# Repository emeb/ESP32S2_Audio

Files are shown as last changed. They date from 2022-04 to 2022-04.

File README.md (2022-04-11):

# ESP32S2_Audio
A Eurorack module demonstrating the use of the ESP32S2 as an audio effects processor

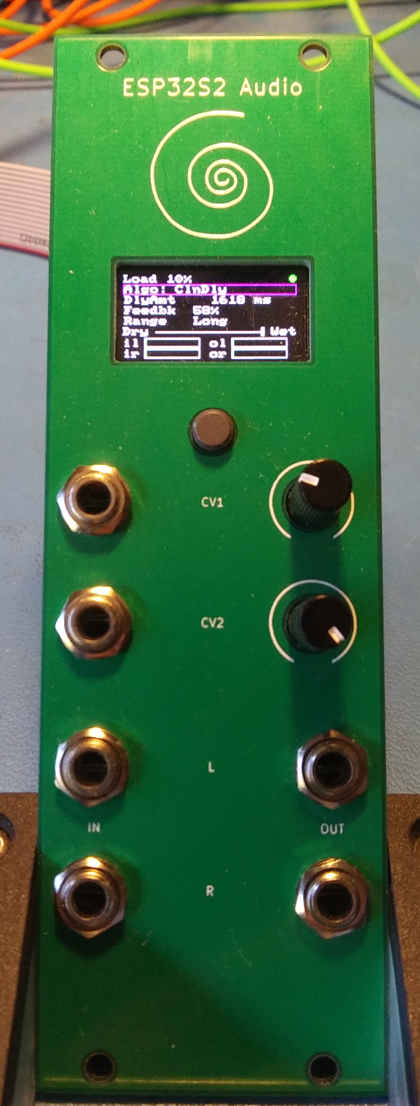
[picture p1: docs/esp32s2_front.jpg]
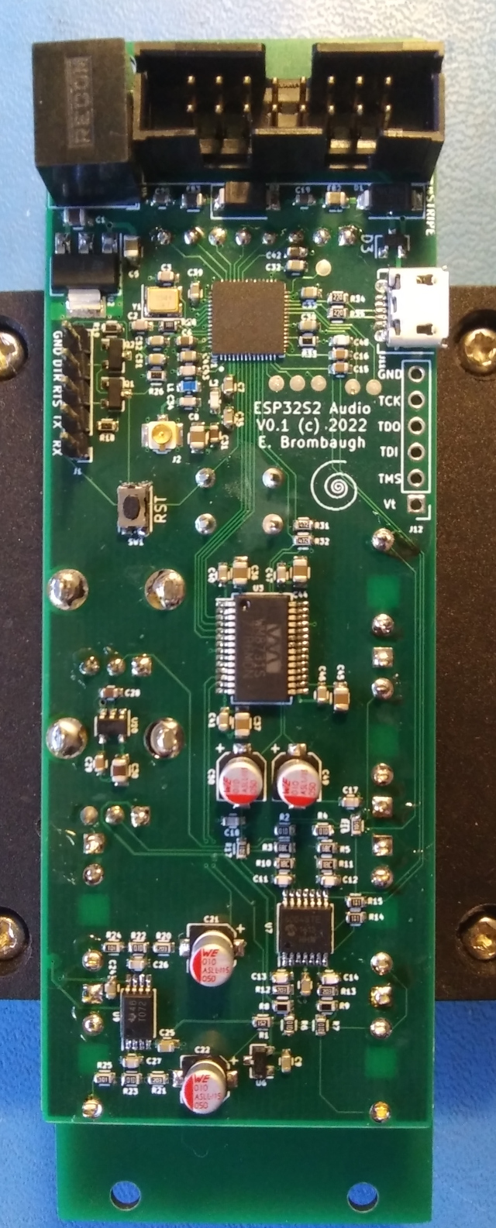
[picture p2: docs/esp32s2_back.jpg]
  

## Abstract
Blah Blah Blah 2020 Microcontroller shortage. See my RP2040_Audio project
if you really want to read all my whinging about this topic:

https://github.com/emeb/RP2040_Audio

So yeah - I've been using STM32 for so long that I was ignoring all this other
stuff that was coming out, including these nifty IoT SoCs (more TLAS pls!) that
so many folks have been using for the lst few years. Espressif has quite a
family of them with a wide variety of capabilities. The ESP32-S2FN4R2 is
especially interesting because it's got 4MB flash and 2MB PSRAM included in
the package and the price is only a few cents more than the raw part. So I
grabbed some devboards, did proof-of-concept on a breadboard and started a
new hardware design. This one is remarkably similar to the RP2040 project
mentioned above - basically I lifted the entire circuit, layout and all and
then proceeded to jack it up on the grease rack and swap the engine out. Here's
the result.

This project is a feasibility study of using the ESP32S2 MCU as an audio effects
processor, with particular emphasis on performance with challenging DSP.

## Hardware
The complete design consists of two PCBs:
* The system PCB - a single board containg all electrical components. Find it
in the Hardware directory.
* The Front Panel - a PCB-based front panel that conforms to the Eurorack
physical mounting standard. Found in the Hardware/esp32s2_panel directory.

The system PCB has the following features:
* Standard Eurorack 16-pin shrouded power connector
* Two +/-5V CV inputs and associated analog signal conditioning 
* Two +/-7V Audio inputs and associated analog signal conditioning 
* Two +/-7V Audio outputs and associated analog drivers
* WM8731 stereo audio codec
* ESP32S2 with 4MB SPI flash, 2MB PSRAM, USB, JTAG and serial interfaces for
development. The RF antenna connection is also available for playing with WiFi
if I ever get around to it.
* 160 x 80 IPS LCD
* UI button

## Firmware
A demonstration firmware is included that exercises all of the capabilities of
the system, including the LCD, UI button, CV inputs and stereo audio I/O. It is
a basic multi-effects unit that supports a complement of audio DSP algorithms
that are easily extended by adding standardized modules to a data structure.
As provided here just three algorithms are available:
* Simple pass-thru with no processing
* Simple gain control
* Basic "clean delay" with crossfaded deglitching during delay changes.

Other algorithms have been tested including phasers, flangers, frequency shifters,
resampling delays and reverbs, but these are not publicly released at this time.

## Findings
The ESP32S2 is not bad for doing audio, but I found it necessary to do a bit of
hacking on their I2S driver - as delivered in their ESP-IDF V5.0 which I used
here the driver makes some limiting assumptions about how you want to do audio:
Namely that you'll be streaming large buffers to/from some external device like
the WiFi interface or storage. That's *NOT* how I do audio - I want small
buffers streaming in realtime with lots of DSP involved. Consequently, I coded
up a "low-latency" driver that works more the way I want and that's included
here.

The ESP32 ADCs are also noisy and a bit weird to use, so my ADC driver has a
rather kludgy approach to collecting data and applies heavy filtering to clean
things up. The lack of hardware floating point was a bit of a stumbling block
and I spent some time converting a few of my algorithms to work with fixed
point. A few others were fine using floating point in software so those were
left alone. The reasonably large PSRAM works well for smaller-sized buffers
in audio delays and found a lot of use in delays.

I found many other aspects of their system quite pleasant to use - the IDF has
a lot of well thought-out services, and the build process is easy to work with.

TL;DR - ESP32S2 can work well for audio effects. Give it a try!

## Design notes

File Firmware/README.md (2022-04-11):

# ESP32S2 Audio Firmware
This directory contains the source and build scripts for the RP2040 Audio
firmware.

## Features
* Simple graphic user interface for selecting and controlling a variety
of audio DSP algorithms.
* Single button and CV navigation through availble effects and settings.
* Non-volatile storage of effects parameters so user settings will survive
power cycling and restore to the previous configuration.
* Storage "pending" indicator.
* CPU Load meter to indicate how hard the system is working.
* Wet/Dry mix indicator.
* Independent input/output VU meters for both channels.

## Usage
* System shows splash screen with version number at power-up.
* Use the single button to select which screen parameter to edit. Current
parameter highlighted with a magenta box drawn around it.
* Use CV #1 to edit the parameter. There is hysteresis and 'snap' so that you
must move the CV to begin changing the value from the previous setting.
* CV #2 is dedicated to the Wet/Dry mix.

## Building
This project is built using the ESP-IDF V5.0 

https://github.com/espressif/esp-idf

Install the SDK and ensure it's working properly, then within this directory

```shell
idf.py build
```

Then use your method of choice for programming the device

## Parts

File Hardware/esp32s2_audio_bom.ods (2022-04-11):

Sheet: esp32s2_audio_bom
Source: | /home/ericb/KBADC/kicad/esp32s2_audio/esp32s2_audio.sch
Date: | Wed 02 Mar 2022 10:13:31 AM MST
Tool: | Eeschema 5.1.12-1.fc34
Generator: | /usr/share/kicad/plugins/bom_csv_grouped_by_value.py
Component Count: | 117
Individual Components:
Item | Qty | Reference(s) | Value | LibPart | Footprint | Datasheet | ambient temperature range high | ambient temperature range low | automotive | bandwidth | category | data rate | device class L1 | device class L2 | device class L3 | digikey description | digikey part number | height | interface | ipc land pattern name | lead free | library id | manufacturer | max frequency | max junction temp | max supply voltage | min supply voltage | mouser part number | nominal supply current | number of ADC channels | number of GPIO | package | receiving current | rohs | sensitivity | standoff height | temperature range high | temperature range low | transmitting current
 |  | C1 | 10uf | Device:C_Small | Capacitors_SMD:C_0805 | ~
 |  | C2 | 27pf | Device:C_Small | Capacitors_SMD:C_0603 | ~
 |  | C3 | 27pf | Device:C_Small | Capacitors_SMD:C_0603 | ~
 |  | C4 | 0.1uf | Device:C_Small | Capacitors_SMD:C_0603 | ~
 |  | C5 | 10uf | Device:C_Small | Capacitors_SMD:C_0805 | ~
 |  | C6 | 1uf | Device:C_Small | Capacitors_SMD:C_0603 | ~
 |  | C7 | 0.1uf | Device:C_Small | Capacitors_SMD:C_0603 | ~
 |  | C8 | 10uf | Device:C_Small | Capacitors_SMD:C_0805 | ~
 |  | C9 | 0.1uf | Device:C_Small | Capacitors_SMD:C_0603 | ~
 |  | C10 | 0.1uf | Device:C_Small | Capacitors_SMD:C_0603 | ~
 |  | C11 | 330pf | Device:C_Small | Capacitors_SMD:C_0603 | ~
 |  | C12 | 330pf | Device:C_Small | Capacitors_SMD:C_0603 | ~
 |  | C13 | 330pf | Device:C_Small | Capacitors_SMD:C_0603 | ~
 |  | C14 | 330pf | Device:C_Small | Capacitors_SMD:C_0603 | ~
 |  | C15 | 0.01uf | Device:C_Small | Capacitors_SMD:C_0603 | ~
 |  | C16 | 0.01uf | Device:C_Small | Capacitors_SMD:C_0603 | ~
 |  | C17 | 220pf | Device:C_Small | Capacitors_SMD:C_0603 | ~
 |  | C18 | 220pf | Device:C_Small | Capacitors_SMD:C_0603 | ~
 |  | C19 | 1uf | Device:C_Small | Capacitors_SMD:C_0603 | ~
 |  | C20 | 1uf | Device:C_Small | Capacitors_SMD:C_0603 | ~
 |  | C21 | 1uf | Device:CP1 | Capacitors_SMD:CP_Elec_4x5.3 | ~
 |  | C22 | 1uf | Device:CP1 | Capacitors_SMD:CP_Elec_4x5.3 | ~
 |  | C24 | 0.1uf | Device:C_Small | Capacitors_SMD:C_0603 | ~
 |  | C25 | 0.1uf | Device:C_Small | Capacitors_SMD:C_0603 | ~
 |  | C26 | 68pf | Device:C_Small | Capacitors_SMD:C_0603 | ~
 |  | C27 | 68pf | Device:C_Small | Capacitors_SMD:C_0603 | ~
 |  | C28 | 1uf | Device:C_Small | Capacitors_SMD:C_0603 | ~
 |  | C29 | 0.01uf | Device:C_Small | Capacitors_SMD:C_0603 | ~
 |  | C30 | 10uf | Device:C_Small | Capacitors_SMD:C_0805 | ~
 |  | C31 | 1uf | Device:C_Small | Capacitors_SMD:C_0603 | ~
 |  | C32 | 0.1uf | Device:C_Small | Capacitors_SMD:C_0603 | ~
 |  | C33 | 0.1uf | Device:C_Small | Capacitors_SMD:C_0603 | ~
 |  | C34 | 2.6pf | Device:C_Small | Capacitors_SMD:C_0603 | ~
 |  | C35 | 0.1uf | Device:C_Small | Capacitors_SMD:C_0603 | ~
 |  | C36 | 10uf | Device:C_Small | Capacitors_SMD:C_0805 | ~
 |  | C37 | 10uf | Device:C_Small | Capacitors_SMD:C_0805 | ~
 |  | C38 | 0.1uf | Device:C_Small | Capacitors_SMD:C_0603 | ~
 |  | C39 | 0.1uf | Device:C_Small | Capacitors_SMD:C_0603 | ~
 |  | C40 | 0.1uf | Device:C_Small | Capacitors_SMD:C_0603 | ~
 |  | C41 | 0.1uf | Device:C_Small | Capacitors_SMD:C_0603 | ~
 |  | C42 | 1uf | Device:C_Small | Capacitors_SMD:C_0603 | ~
 |  | C43 | 3pf | Device:C_Small | Capacitors_SMD:C_0603 | ~
 |  | C44 | 10uf | Device:C_Small | Capacitors_SMD:C_0805 | ~
 |  | C45 | 10uf | Device:C_Small | Capacitors_SMD:C_0805 | ~
 |  | C46 | 0.1uf | Device:C_Small | Capacitors_SMD:C_0603 | ~
 |  | C47 | 0.1uf | Device:C_Small | Capacitors_SMD:C_0603 | ~
 |  | C48 | 330pf | Device:C_Small | Capacitors_SMD:C_0603 | ~
 |  | C49 | 1uf | Device:CP1 | Capacitors_SMD:CP_Elec_4x5.3 | ~
 |  | C50 | 1uf | Device:CP1 | Capacitors_SMD:CP_Elec_4x5.3 | ~
 |  | C51 | 0.1uf | Device:C_Small | Capacitors_SMD:C_0603 | ~
 |  | C52 | 100pf | Device:C_Small | Capacitors_SMD:C_0603 | ~
 |  | D1 | D | Device:D | Diodes_SMD:D_SMA | ~
 |  | D2 | D | Device:D | Diodes_SMD:D_SMA | ~
 |  | D3 | BAT54C | Diode:BAT54C | Package_TO_SOT_SMD:SOT-23 | http://www.diodes.com/_files/datasheets/ds11005.pdf
 |  | FB2 | 220 | Device:Ferrite_Bead_Small | Resistors_SMD:R_0805 | ~
 |  | FB3 | 220 | Device:Ferrite_Bead_Small | Resistors_SMD:R_0805 | ~
 |  | J1 | Serial | Connector_Generic:Conn_01x05 | Pin_Headers:Pin_Header_Straight_1x05_Pitch2.54mm | ~
 |  | J2 | CONN_CONUFL001-SMD-T_LNX | emeb_library:CONN_CONUFL001-SMD-T_LNX | footprints:CONUFL001-SMD-T | ~
 |  | J3 | LCD | Connector_Generic:Conn_01x08 | footprints:LCD_80x160_0.96 | ~
 |  | J4 | AudioJack2_SwitchT | Connector:AudioJack2_SwitchT | footprints:Jack_3.5mm_QingPu_WQP-PJ398SM_Vertical_CircularHoles | ~
 |  | J5 | AudioJack2_SwitchT | Connector:AudioJack2_SwitchT | footprints:Jack_3.5mm_QingPu_WQP-PJ398SM_Vertical_CircularHoles | ~
 |  | J6 | AudioJack2_SwitchT | Connector:AudioJack2_SwitchT | footprints:Jack_3.5mm_QingPu_WQP-PJ398SM_Vertical_CircularHoles | ~
 |  | J7 | AudioJack2_SwitchT | Connector:AudioJack2_SwitchT | footprints:Jack_3.5mm_QingPu_WQP-PJ398SM_Vertical_CircularHoles | ~
 |  | J8 | Conn_02x08_Odd_Even | Connector_Generic:Conn_02x08_Odd_Even | footprints:5103308-3 | ~
 |  | J9 | AudioJack2_SwitchT | Connector:AudioJack2_SwitchT | footprints:Jack_3.5mm_QingPu_WQP-PJ398SM_Vertical_CircularHoles | ~
 |  | J10 | AudioJack2_SwitchT | Connector:AudioJack2_SwitchT | footprints:Jack_3.5mm_QingPu_WQP-PJ398SM_Vertical_CircularHoles | ~
 |  | J11 | USB_B_Micro | Connector:USB_B_Micro | footprints:USB_Micro-B_10103594-0001LF_actual_outline | ~
 |  | J12 | JTAG | Connector_Generic:Conn_01x06 | Pin_Headers:Pin_Header_Straight_1x06_Pitch2.54mm | ~
 |  | L1 | 2.4nH | Device:L | Capacitor_SMD:C_0603_1608Metric | ~
 |  | L2 | 2.2nH 500ma | Device:L | Capacitor_SMD:C_0603_1608Metric | ~
 |  | Q1 | MMBT3904 | Device:Q_NPN_BEC | TO_SOT_Packages_SMD:SOT-23 | ~
 |  | Q2 | MMBT3904 | Device:Q_NPN_BEC | TO_SOT_Packages_SMD:SOT-23 | ~
 |  | R1 | 1.5k | Device:R | Resistors_SMD:R_0603 | ~
 |  | R2 | 100k | Device:R | Resistors_SMD:R_0603 | ~
 |  | R3 | 49.9k | Device:R | Resistors_SMD:R_0603 | ~
 |  | R4 | 100k | Device:R | Resistors_SMD:R_0603 | ~
 |  | R5 | 49.9k | Device:R | Resistors_SMD:R_0603 | ~
 |  | R6 | 100k | Device:R | Resistors_SMD:R_0603 | ~
 |  | R7 | 100k | Device:R | Resistors_SMD:R_0603 | ~
 |  | R8 | 60.4k | Device:R | Resistors_SMD:R_0603 | ~
 |  | R9 | 60.4k | Device:R | Resistors_SMD:R_0603 | ~
 |  | R10 | 33k | Device:R | Resistors_SMD:R_0603 | ~
 |  | R11 | 33k | Device:R | Resistors_SMD:R_0603 | ~
 |  | R12 | 20k | Device:R | Resistors_SMD:R_0603 | ~
 |  | R13 | 20k | Device:R | Resistors_SMD:R_0603 | ~
 |  | R14 | 180 | Device:R | Resistors_SMD:R_0603 | ~
 |  | R15 | 180 | Device:R | Resistors_SMD:R_0603 | ~
 |  | R16 | 100 | Device:R | Resistors_SMD:R_0603 | ~
 |  | R17 | 100 | Device:R | Resistors_SMD:R_0603 | ~
 |  | R18 | 10k | Device:R | Resistors_SMD:R_0603 | ~
 |  | R19 | 10k | Device:R | Resistors_SMD:R_0603 | ~
 |  | R20 | 20k | Device:R | Resistors_SMD:R_0603 | ~
 |  | R21 | 20k | Device:R | Resistors_SMD:R_0603 | ~
 |  | R22 | 100k | Device:R | Resistors_SMD:R_0603 | ~
 |  | R23 | 100k | Device:R | Resistors_SMD:R_0603 | ~
 |  | R24 | 100 | Device:R | Resistors_SMD:R_0603 | ~
 |  | R25 | 100 | Device:R | Resistors_SMD:R_0603 | ~
 |  | R26 | 10k | Device:R | Resistors_SMD:R_0603 | ~
 |  | R28 | 1k | Device:R | Resistors_SMD:R_0603 | ~
 |  | R31 | 4.7k | Device:R | Resistors_SMD:R_0603 | ~
 |  | R32 | 4.7k | Device:R | Resistors_SMD:R_0603 | ~
 |  | R33 | 49 | Device:R | Resistors_SMD:R_0603 | ~
 |  | R34 | 27.5 | Device:R | Resistors_SMD:R_0603 | ~
 |  | R35 | 27.5 | Device:R | Resistors_SMD:R_0603 | ~
 |  | RV1 | 10k | Device:R_POT | footprints:Potentiometer_TT_P0915N | ~
 |  | RV2 | 10k | Device:R_POT | footprints:Potentiometer_TT_P0915N | ~
 |  | SW1 | SW_Push | Switch:SW_Push | Buttons_Switches_SMD:SW_SPST_KMR2 | ~
 |  | SW4 | SW_Push | Switch:SW_Push | footprints:SW_PUSH_6mm_Center | ~
 |  | U1 | ESP32-S2 | emeb_library:ESP32-S2_emeb | footprints:Espressif_Systems-ESP32-S2-IPC_A | https://www.espressif.com/sites/default/files/documentation/esp32-s2_datasheet_en.pdf | +105Â°C | -40Â°C | No | 40MHz | IC | 150Mbits/s | Integrated Circuits (ICs) | RF Semiconductors and Devices | Transceivers | RX TXRX MOD WIFI SURFACE MOUNT | 1965-ESP32-S2TR-ND | 0.9mm | I2C,SPI,UART,USB,I2S,Other | QFN40P700X700X85-56 | Yes | aeb43a67ce7aabf7 | Espressif Systems | 2.4GHz | +125Â°C | 3.6V | 1.8V | 356-ESP32-S2 | 0.5A | 20 | 43 | QFN56 | 68mA | Yes | -97dBm | 0mm | +105Â°C | -40Â°C | 310mA
 |  | U2 | LD1117S33TR_SOT223 | Regulator_Linear:LD1117S33TR_SOT223 | Package_TO_SOT_SMD:SOT-223-3_TabPin2 | http://www.st.com/st-web-ui/static/active/en/resource/technical/document/datasheet/CD00000544.pdf
 |  | U3 | WM8731 | emeb_library:WM8731 | Housings_SSOP:SSOP-28_5.3x10.2mm_Pitch0.65mm
 |  | U4 | R-78E5.0-0.5 | emeb_library:R-78E5.0-0.5 | Converter_DCDC:Converter_DCDC_RECOM_R-78E-0.5_THT | https://www.recom-power.com/pdf/Innoline/R-78Exx-0.5.pdf
 |  | U6 | LM4040DBZ-5 | Reference_Voltage:LM4040DBZ-5 | Package_TO_SOT_SMD:SOT-23 | http://www.ti.com/lit/ds/symlink/lm4040-n.pdf
 |  | U7 | MCP6004 | Amplifier_Operational:MCP6004 | Housings_SSOP:TSSOP-14_4.4x5mm_Pitch0.65mm | http://www.ti.com/lit/ds/symlink/tl081.pdf
 |  | U9 | TL072PW | Amplifier_Operational:TL082 | Housings_SSOP:TSSOP-8_4.4x3mm_Pitch0.65mm | http://www.ti.com/lit/ds/symlink/tl081.pdf
 |  | U10 | LP2985-3.3 | Regulator_Linear:LP2985-3.3 | TO_SOT_Packages_SMD:SOT-23-5 | http://www.ti.com/lit/ds/symlink/lp2985.pdf
 |  | Y1 | Crystal_4pin_SMD | emeb_library:Crystal_4pin_SMD | Crystals:Crystal_SMD_3225-4pin_3.2x2.5mm
Collated Components:
Item | Qty | Reference(s) | Value | LibPart | Footprint | Datasheet | ambient temperature range high | ambient temperature range low | automotive | bandwidth | category | data rate | device class L1 | device class L2 | device class L3 | digikey description | digikey part number | height | interface | ipc land pattern name | lead free | library id | manufacturer | max frequency | max junction temp | max supply voltage | min supply voltage | mouser part number | nominal supply current | number of ADC channels | number of GPIO | package | receiving current | rohs | sensitivity | standoff height | temperature range high | temperature range low | transmitting current
1 | 8 | C1, C5, C8, C30, C36, C37, C44, C45 | 10uf | Device:C_Small | Capacitors_SMD:C_0805 | ~
2 | 2 | C2, C3 | 27pf | Device:C_Small | Capacitors_SMD:C_0603 | ~
3 | 16 | C4, C7, C9, C10, C24, C25, C32, C33, C35, C38, C39, C40, C41, C46, C47, C51 | 0.1uf | Device:C_Small | Capacitors_SMD:C_0603 | ~
4 | 6 | C6, C19, C20, C28, C31, C42 | 1uf | Device:C_Small | Capacitors_SMD:C_0603 | ~
5 | 5 | C11, C12, C13, C14, C48 | 330pf | Device:C_Small | Capacitors_SMD:C_0603 | ~
6 | 3 | C15, C16, C29 | 0.01uf | Device:C_Small | Capacitors_SMD:C_0603 | ~
7 | 2 | C17, C18 | 220pf | Device:C_Small | Capacitors_SMD:C_0603 | ~
8 | 4 | C21, C22, C49, C50 | 1uf | Device:CP1 | Capacitors_SMD:CP_Elec_4x5.3 | ~
9 | 2 | C26, C27 | 68pf | Device:C_Small | Capacitors_SMD:C_0603 | ~
10 | 1 | C34 | 2.6pf | Device:C_Small | Capacitors_SMD:C_0603 | ~
11 | 1 | C43 | 3pf | Device:C_Small | Capacitors_SMD:C_0603 | ~
12 | 1 | C52 | 100pf | Device:C_Small | Capacitors_SMD:C_0603 | ~
13 | 2 | D1, D2 | D | Device:D | Diodes_SMD:D_SMA | ~
14 | 1 | D3 | BAT54C | Diode:BAT54C | Package_TO_SOT_SMD:SOT-23 | http://www.diodes.com/_files/datasheets/ds11005.pdf
15 | 2 | FB2, FB3 | 220 | Device:Ferrite_Bead_Small | Resistors_SMD:R_0805 | ~
16 | 1 | J1 | Serial | Connector_Generic:Conn_01x05 | Pin_Headers:Pin_Header_Straight_1x05_Pitch2.54mm | ~
17 | 1 | J2 | CONN_CONUFL001-SMD-T_LNX | emeb_library:CONN_CONUFL001-SMD-T_LNX | footprints:CONUFL001-SMD-T | ~
18 | 1 | J3 | LCD | Connector_Generic:Conn_01x08 | footprints:LCD_80x160_0.96 | ~
19 | 6 | J4, J5, J6, J7, J9, J10 | AudioJack2_SwitchT | Connector:AudioJack2_SwitchT | footprints:Jack_3.5mm_QingPu_WQP-PJ398SM_Vertical_CircularHoles | ~
20 | 1 | J8 | Conn_02x08_Odd_Even | Connector_Generic:Conn_02x08_Odd_Even | footprints:5103308-3 | ~
21 | 1 | J11 | USB_B_Micro | Connector:USB_B_Micro | footprints:USB_Micro-B_10103594-0001LF_actual_outline | ~
22 | 1 | J12 | JTAG | Connector_Generic:Conn_01x06 | Pin_Headers:Pin_Header_Straight_1x06_Pitch2.54mm | ~
23 | 1 | L1 | 2.4nH | Device:L | Capacitor_SMD:C_0603_1608Metric | ~
24 | 1 | L2 | 2.2nH 500ma | Device:L | Capacitor_SMD:C_0603_1608Metric | ~
25 | 2 | Q1, Q2 | MMBT3904 | Device:Q_NPN_BEC | TO_SOT_Packages_SMD:SOT-23 | ~
26 | 1 | R1 | 1.5k | Device:R | Resistors_SMD:R_0603 | ~
27 | 6 | R2, R4, R6, R7, R22, R23 | 100k | Device:R | Resistors_SMD:R_0603 | ~
28 | 2 | R3, R5 | 49.9k | Device:R | Resistors_SMD:R_0603 | ~
29 | 2 | R8, R9 | 60.4k | Device:R | Resistors_SMD:R_0603 | ~
30 | 2 | R10, R11 | 33k | Device:R | Resistors_SMD:R_0603 | ~
31 | 4 | R12, R13, R20, R21 | 20k | Device:R | Resistors_SMD:R_0603 | ~
32 | 2 | R14, R15 | 180 | Device:R | Resistors_SMD:R_0603 | ~
33 | 4 | R16, R17, R24, R25 | 100 | Device:R | Resistors_SMD:R_0603 | ~
34 | 3 | R18, R19, R26 | 10k | Device:R | Resistors_SMD:R_0603 | ~
35 | 1 | R28 | 1k | Device:R | Resistors_SMD:R_0603 | ~
36 | 2 | R31, R32 | 4.7k | Device:R | Resistors_SMD:R_0603 | ~
37 | 1 | R33 | 49 | Device:R | Resistors_SMD:R_0603 | ~
38 | 2 | R34, R35 | 27.5 | Device:R | Resistors_SMD:R_0603 | ~
39 | 2 | RV1, RV2 | 10k | Device:R_POT | footprints:Potentiometer_TT_P0915N | ~
40 | 1 | SW1 | SW_Push | Switch:SW_Push | Buttons_Switches_SMD:SW_SPST_KMR2 | ~
41 | 1 | SW4 | SW_Push | Switch:SW_Push | footprints:SW_PUSH_6mm_Center | ~
42 | 1 | U1 | ESP32-S2 | emeb_library:ESP32-S2_emeb | footprints:Espressif_Systems-ESP32-S2-IPC_A | https://www.espressif.com/sites/default/files/documentation/esp32-s2_datasheet_en.pdf | +105Â°C | -40Â°C | No | 40MHz | IC | 150Mbits/s | Integrated Circuits (ICs) | RF Semiconductors and Devices | Transceivers | RX TXRX MOD WIFI SURFACE MOUNT | 1965-ESP32-S2TR-ND | 0.9mm | I2C,SPI,UART,USB,I2S,Other | QFN40P700X700X85-56 | Yes | aeb43a67ce7aabf7 | Espressif Systems | 2.4GHz | +125Â°C | 3.6V | 1.8V | 356-ESP32-S2 | 0.5A | 20 | 43 | QFN56 | 68mA | Yes | -97dBm | 0mm | +105Â°C | -40Â°C | 310mA
43 | 1 | U2 | LD1117S33TR_SOT223 | Regulator_Linear:LD1117S33TR_SOT223 | Package_TO_SOT_SMD:SOT-223-3_TabPin2 | http://www.st.com/st-web-ui/static/active/en/resource/technical/document/datasheet/CD00000544.pdf
44 | 1 | U3 | WM8731 | emeb_library:WM8731 | Housings_SSOP:SSOP-28_5.3x10.2mm_Pitch0.65mm
45 | 1 | U4 | R-78E5.0-0.5 | emeb_library:R-78E5.0-0.5 | Converter_DCDC:Converter_DCDC_RECOM_R-78E-0.5_THT | https://www.recom-power.com/pdf/Innoline/R-78Exx-0.5.pdf
46 | 1 | U6 | LM4040DBZ-5 | Reference_Voltage:LM4040DBZ-5 | Package_TO_SOT_SMD:SOT-23 | http://www.ti.com/lit/ds/symlink/lm4040-n.pdf
47 | 1 | U7 | MCP6004 | Amplifier_Operational:MCP6004 | Housings_SSOP:TSSOP-14_4.4x5mm_Pitch0.65mm | http://www.ti.com/lit/ds/symlink/tl081.pdf
48 | 1 | U9 | TL072PW | Amplifier_Operational:TL082 | Housings_SSOP:TSSOP-8_4.4x3mm_Pitch0.65mm | http://www.ti.com/lit/ds/symlink/tl081.pdf
49 | 1 | U10 | LP2985-3.3 | Regulator_Linear:LP2985-3.3 | TO_SOT_Packages_SMD:SOT-23-5 | http://www.ti.com/lit/ds/symlink/lp2985.pdf
50 | 1 | Y1 | Crystal_4pin_SMD | emeb_library:Crystal_4pin_SMD | Crystals:Crystal_SMD_3225-4pin_3.2x2.5mm

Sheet: Sheet2
Item | Qty | Reference(s) | Value | Footprint
1 | 8 | C1, C5, C8, C30, C36, C37, C44, C45 | 10uf | Capacitors_SMD:C_0805
2 | 2 | C2, C3 | 27pf | Capacitors_SMD:C_0603
3 | 16 | C4, C7, C9, C10, C24, C25, C32, C33, C35, C38, C39, C40, C41, C46, C47, C51 | 0.1uf | Capacitors_SMD:C_0603
4 | 6 | C6, C19, C20, C28, C31, C42 | 1uf | Capacitors_SMD:C_0603
5 | 5 | C11, C12, C13, C14, C48 | 330pf | Capacitors_SMD:C_0603
6 | 3 | C15, C16, C29 | 0.01uf | Capacitors_SMD:C_0603
7 | 2 | C17, C18 | 220pf | Capacitors_SMD:C_0603
8 | 4 | C21, C22, C49, C50 | 1uf | Capacitors_SMD:CP_Elec_4x5.3
9 | 2 | C26, C27 | 68pf | Capacitors_SMD:C_0603
10 | 1 | C34 | 2.6pf | Capacitors_SMD:C_0603
11 | 1 | C43 | 3pf | Capacitors_SMD:C_0603
12 | 1 | C52 | 100pf | Capacitors_SMD:C_0603
13 | 2 | D1, D2 | D | Diodes_SMD:D_SMA
14 | 1 | D3 | BAT54C | Package_TO_SOT_SMD:SOT-23
15 | 2 | FB2, FB3 | 220 | Resistors_SMD:R_0805
16 | 1 | J1 | Serial | Pin_Headers:Pin_Header_Straight_1x05_Pitch2.54mm
17 | 1 | J2 | CONN_CONUFL001-SMD-T_LNX | footprints:CONUFL001-SMD-T
18 | 1 | J3 | LCD | footprints:LCD_80x160_0.96
19 | 6 | J4, J5, J6, J7, J9, J10 | AudioJack2_SwitchT | footprints:Jack_3.5mm_QingPu_WQP-PJ398SM_Vertical_CircularHoles
20 | 1 | J8 | Conn_02x08_Odd_Even | footprints:5103308-3
21 | 1 | J11 | USB_B_Micro | footprints:USB_Micro-B_10103594-0001LF_actual_outline
22 | 1 | J12 | JTAG | Pin_Headers:Pin_Header_Straight_1x06_Pitch2.54mm
23 | 1 | L1 | 2.4nH | Capacitor_SMD:C_0603_1608Metric
24 | 1 | L2 | 2.2nH 500ma | Capacitor_SMD:C_0603_1608Metric
25 | 2 | Q1, Q2 | MMBT3904 | TO_SOT_Packages_SMD:SOT-23
26 | 1 | R1 | 1.5k | Resistors_SMD:R_0603
27 | 6 | R2, R4, R6, R7, R22, R23 | 100k | Resistors_SMD:R_0603
28 | 2 | R3, R5 | 49.9k | Resistors_SMD:R_0603
29 | 2 | R8, R9 | 60.4k | Resistors_SMD:R_0603
30 | 2 | R10, R11 | 33k | Resistors_SMD:R_0603
31 | 4 | R12, R13, R20, R21 | 20k | Resistors_SMD:R_0603
32 | 2 | R14, R15 | 180 | Resistors_SMD:R_0603
33 | 4 | R16, R17, R24, R25 | 100 | Resistors_SMD:R_0603
34 | 3 | R18, R19, R26 | 10k | Resistors_SMD:R_0603
35 | 1 | R28 | 1k | Resistors_SMD:R_0603
36 | 2 | R31, R32 | 4.7k | Resistors_SMD:R_0603
37 | 1 | R33 | 49 | Resistors_SMD:R_0603
38 | 2 | R34, R35 | 27.5 | Resistors_SMD:R_0603
39 | 2 | RV1, RV2 | 10k | footprints:Potentiometer_TT_P0915N
40 | 1 | SW1 | SW_Push | Buttons_Switches_SMD:SW_SPST_KMR2
41 | 1 | SW4 | SW_Push | footprints:SW_PUSH_6mm_Center
42 | 1 | U1 | ESP32-S2 | footprints:Espressif_Systems-ESP32-S2-IPC_A
43 | 1 | U2 | LD1117S33TR_SOT223 | Package_TO_SOT_SMD:SOT-223-3_TabPin2
44 | 1 | U3 | WM8731 | Housings_SSOP:SSOP-28_5.3x10.2mm_Pitch0.65mm
45 | 1 | U4 | R-78E5.0-0.5 | Converter_DCDC:Converter_DCDC_RECOM_R-78E-0.5_THT
46 | 1 | U6 | LM4040DBZ-5 | Package_TO_SOT_SMD:SOT-23
47 | 1 | U7 | MCP6004 | Housings_SSOP:TSSOP-14_4.4x5mm_Pitch0.65mm
48 | 1 | U9 | TL072PW | Housings_SSOP:TSSOP-8_4.4x3mm_Pitch0.65mm
49 | 1 | U10 | LP2985-3.3 | TO_SOT_Packages_SMD:SOT-23-5
50 | 1 | Y1 | Crystal_4pin_SMD | Crystals:Crystal_SMD_3225-4pin_3.2x2.5mm

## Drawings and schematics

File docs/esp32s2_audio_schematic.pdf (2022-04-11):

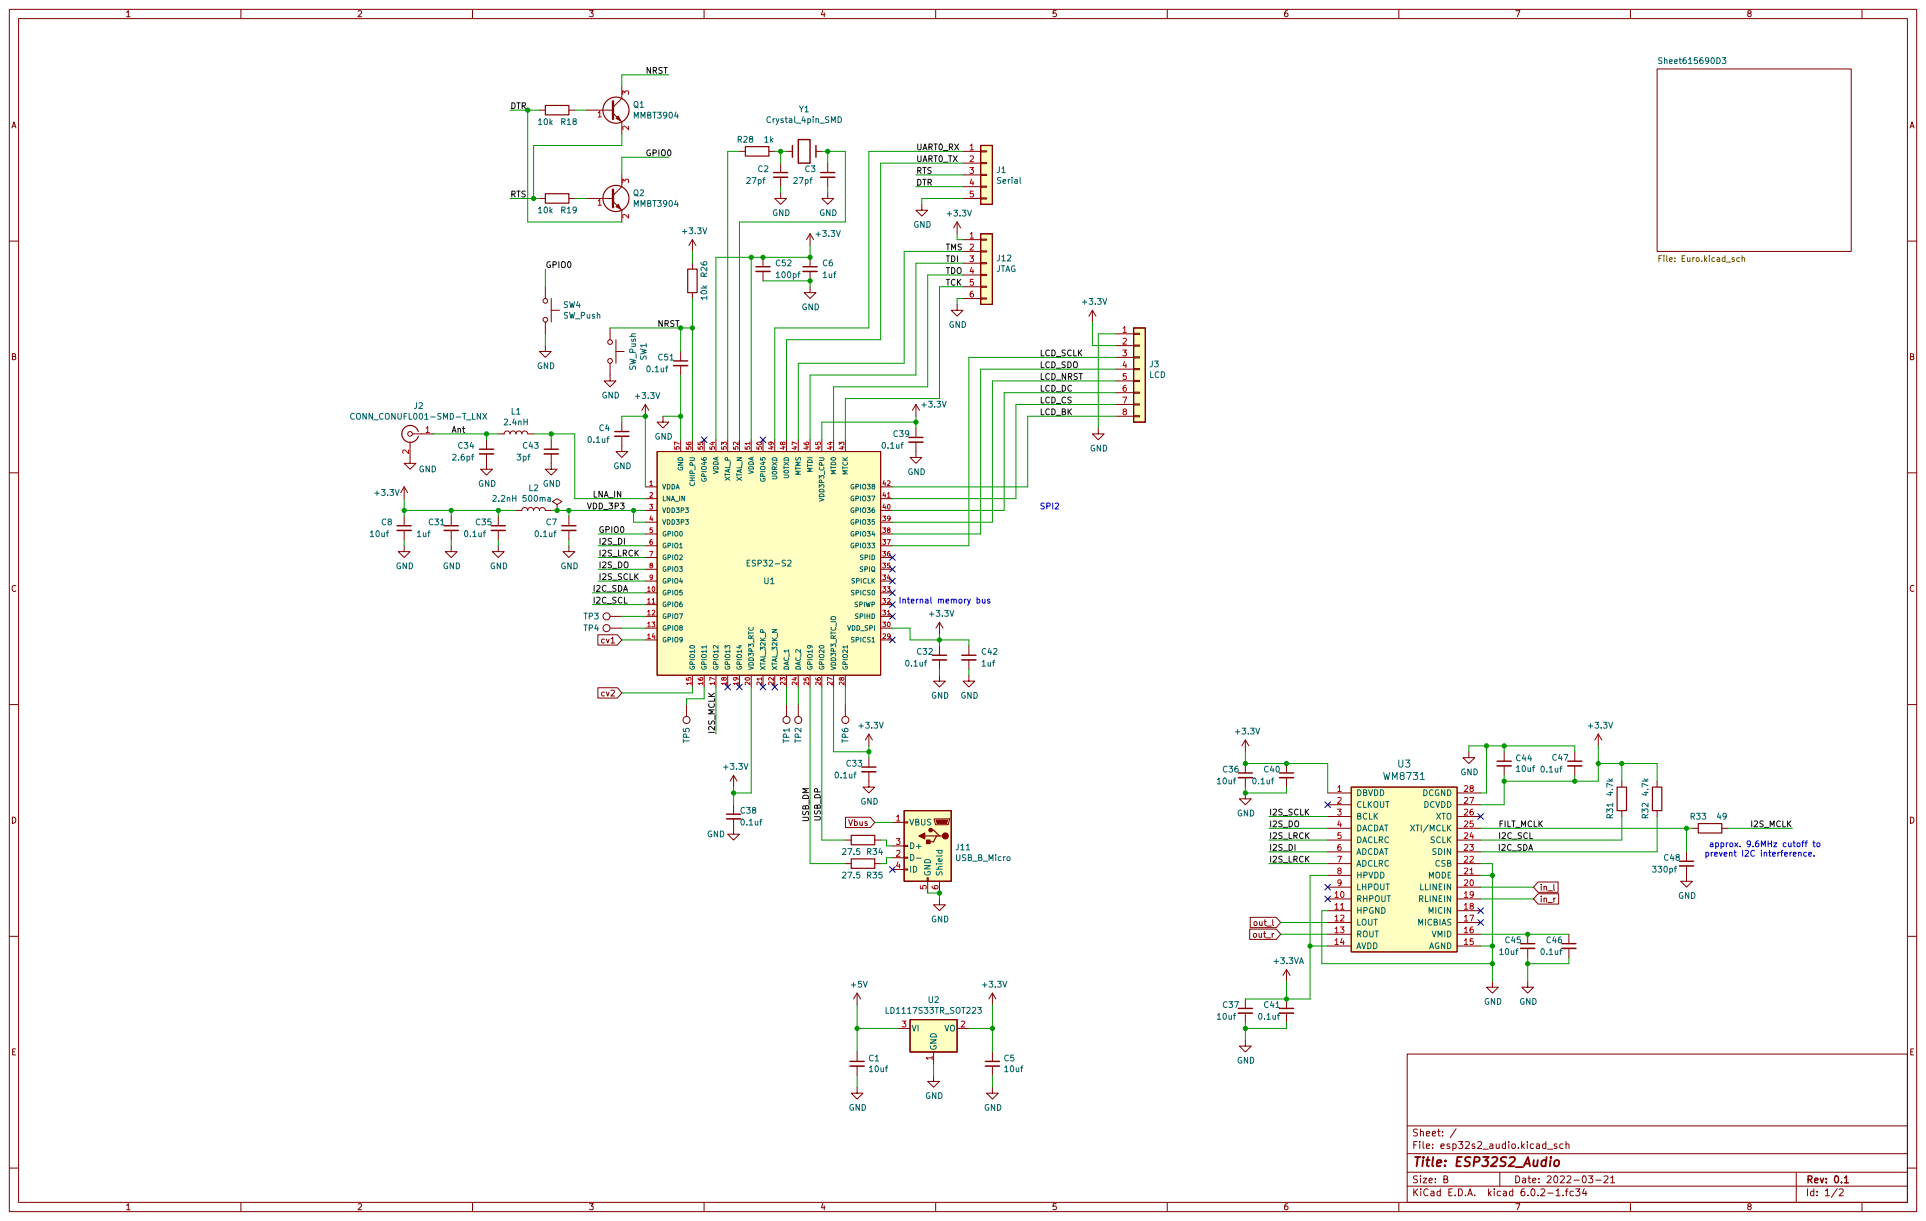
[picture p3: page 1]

LCD_SDO
LCD_NRST
LCD_DC
LCD_CS
LCD_BK

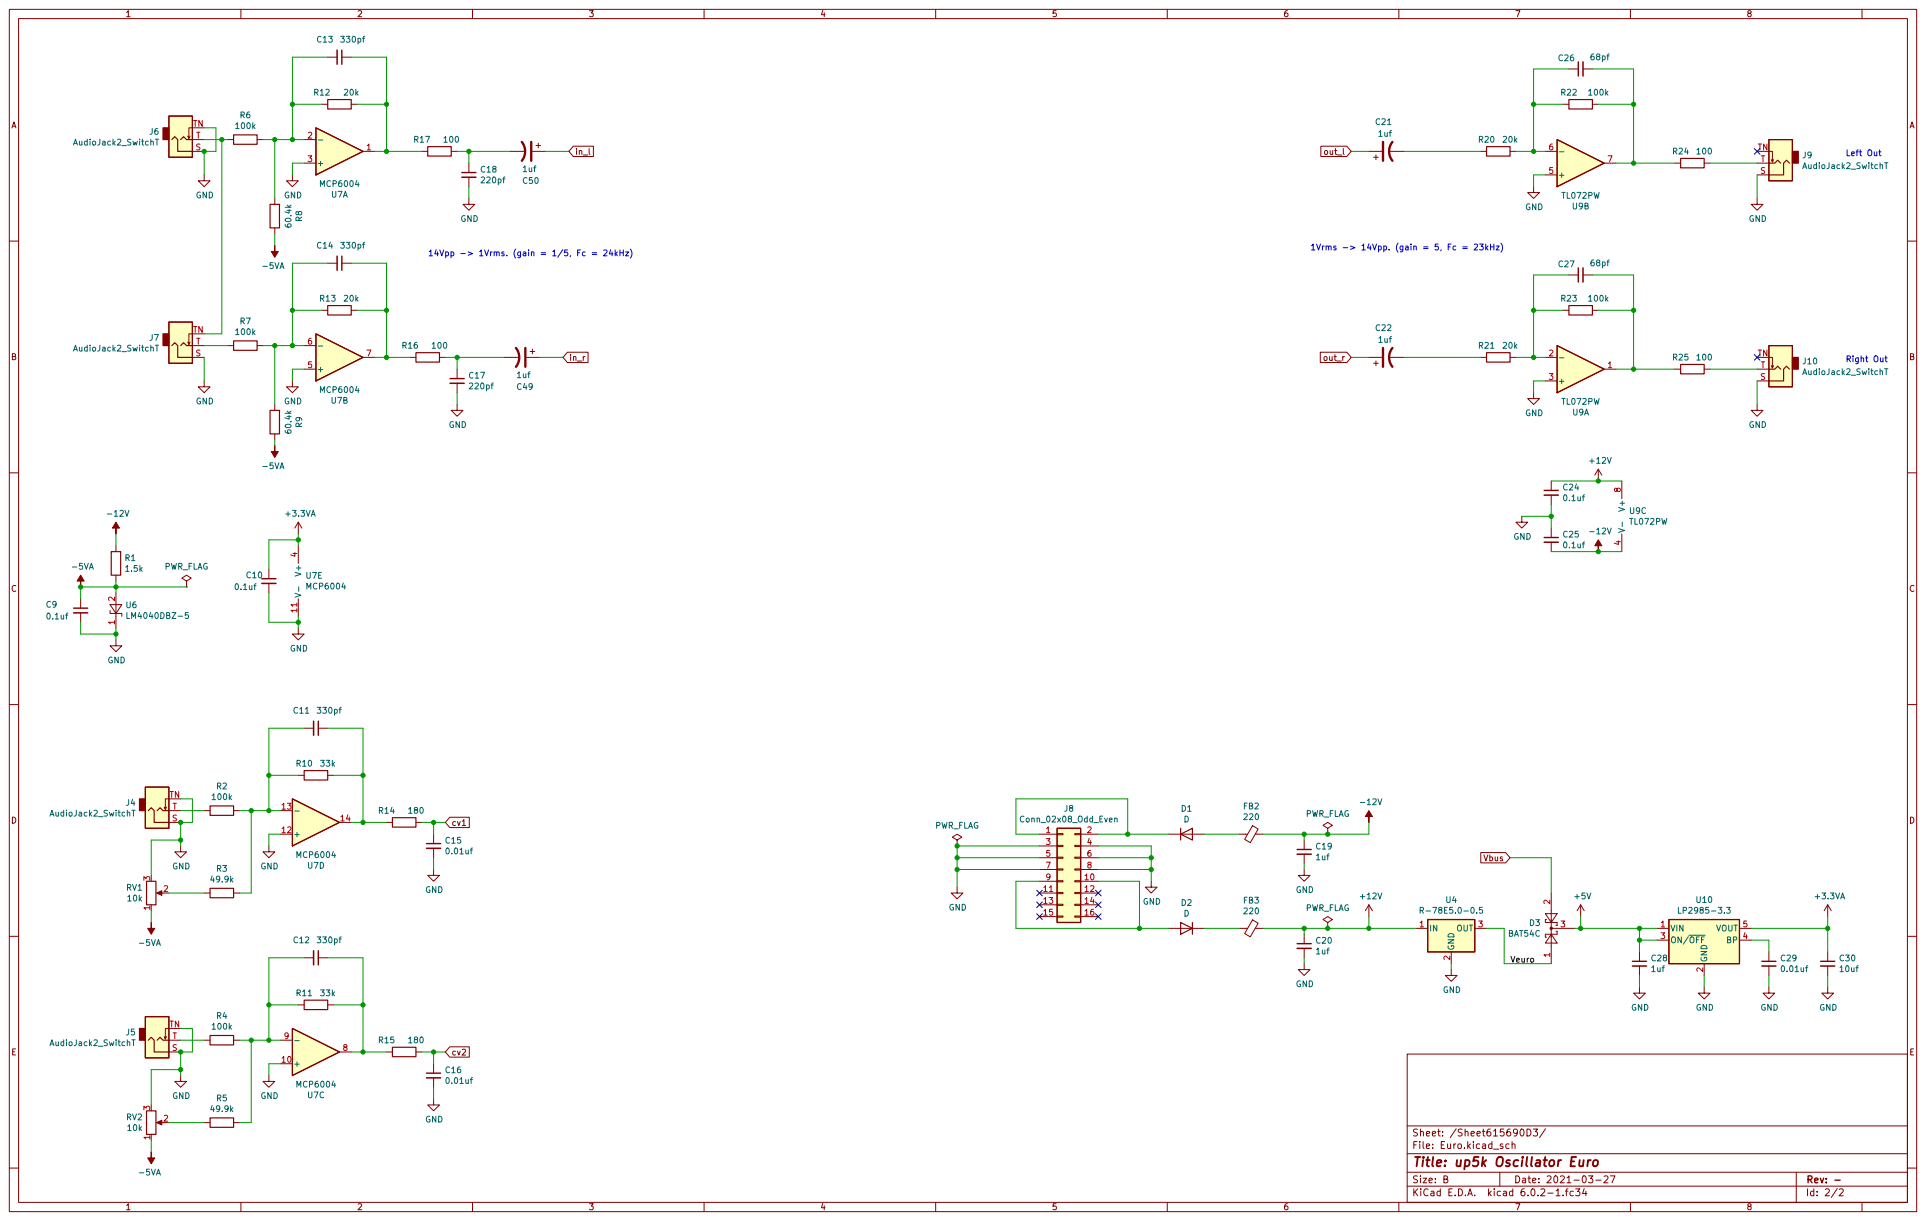
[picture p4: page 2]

9 | 10

File: Euro.kicad_sch Sheet: /Sheet615690D3/
Id: 2/2 Title: up5k Oscillator Euro

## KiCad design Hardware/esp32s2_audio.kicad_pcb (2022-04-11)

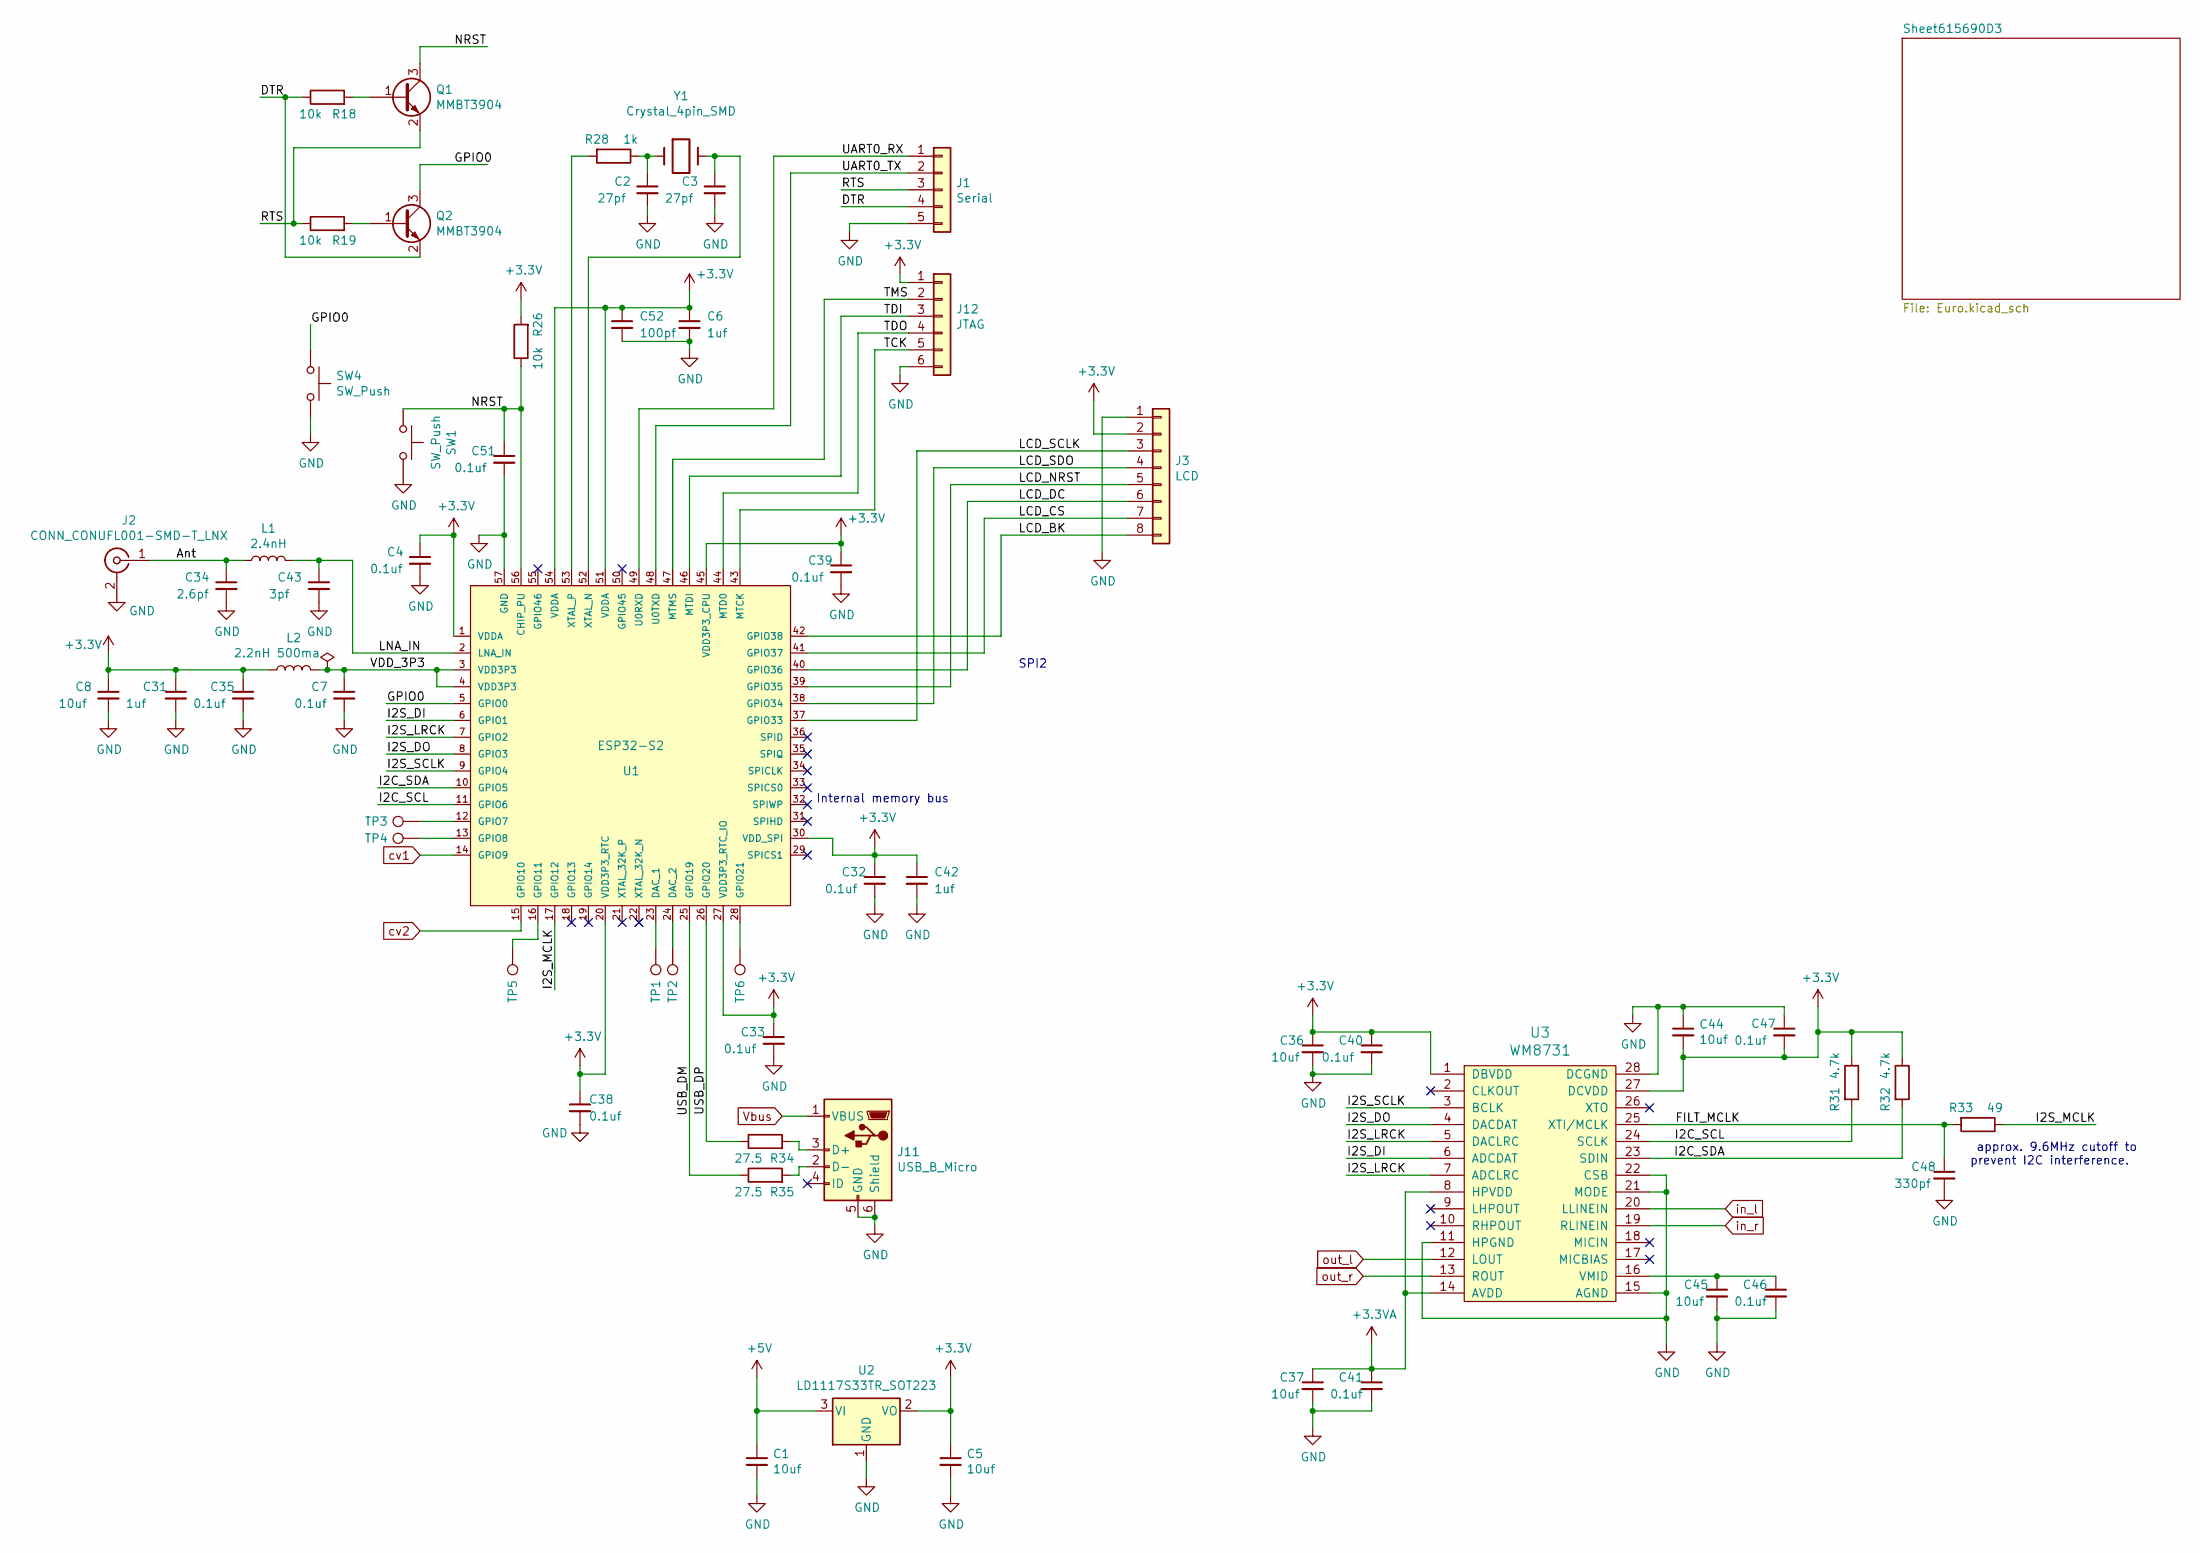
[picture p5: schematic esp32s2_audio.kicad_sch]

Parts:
C1, C5, C8, C36, C37, C44, C45: 10uf; C_0805
C2, C3: 27pf; C_0603
C4, C7, C32, C33, C35, C38, C39, C40, C41, C46, C47, C51: 0.1uf; C_0603
C6, C31, C42: 1uf; C_0603
C34: 2.6pf; C_0603
C43: 3pf; C_0603
C48: 330pf; C_0603
C52: 100pf; C_0603
J1: Serial; Pin_Header_Straight_1x05_Pitch2.54mm
J2: CONN_CONUFL001-SMD-T_LNX; CONUFL001-SMD-T
J3: LCD; LCD_80x160_0.96
J11: USB_B_Micro; USB_Micro-B_10103594-0001LF_actual_outline
J12: JTAG; Pin_Header_Straight_1x06_Pitch2.54mm
L1: 2.4nH; C_0603_1608Metric
L2: 2.2nH 500ma; C_0603_1608Metric
Q1, Q2: MMBT3904; SOT-23
R18, R19, R26: 10k; R_0603
R28: 1k; R_0603
R31, R32: 4.7k; R_0603
R33: 49; R_0603
R34, R35: 27.5; R_0603
SW1: SW_Push; SW_SPST_KMR2
SW4: SW_Push; SW_PUSH_6mm_Center
TP1, TP2, TP3, TP4, TP5, TP6: TestPoint; Measurement_Point_Round-SMD-Pad_Small
U1: ESP32-S2; Espressif_Systems-ESP32-S2-IPC_A; mouser part number 356-ESP32-S2; digikey description RX TXRX MOD WIFI SURFACE MOUNT
U2: LD1117S33TR_SOT223; SOT-223-3_TabPin2
U3: WM8731; SSOP-28_5.3x10.2mm_Pitch0.65mm
Y1: Crystal_4pin_SMD; Crystal_SMD_3225-4pin_3.2x2.5mm

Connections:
+3.3VA: C37.1, C41.1, U3.8 (HPVDD), U3.14 (AVDD); also elsewhere on the board
+3V3: C4.1, C5.1, C6.1, C8.1, C31.1, C32.1, C33.1, C35.1, C36.1, C38.1, C39.1, C40.1, C42.1, C44.2, C47.2, C52.1, J3.2, J12.1, L2.1, R26.2, R31.1, R32.1, U1.1 (VDDA), U1.20 (VDD3P3_RTC), U1.27 (VDD3P3_RTC_IO), U1.30 (VDD_SPI), U1.45 (VDD3P3_CPU), U1.51 (VDDA), U1.54 (VDDA), U2.2 (VO), U3.1 (DBVDD), U3.27 (DCVDD)
+5V: C1.1, U2.3 (VI); also elsewhere on the board
/Ant: C34.1, J2.1 (SIG), L1.1
/DTR: J1.4, Q2.2 (E), R18.1
/FILT_MCLK: C48.1, R33.2, U3.25 (XTI/MCLK)
/GPIO0: Q2.3 (C), SW4.1, U1.5 (GPIO0)
/I2C_SCL: R31.2, U1.11 (GPIO6), U3.24 (SCLK)
/I2C_SDA: R32.2, U1.10 (GPIO5), U3.23 (SDIN)
/I2S_DI: U1.6 (GPIO1), U3.6 (ADCDAT)
/I2S_DO: U1.8 (GPIO3), U3.4 (DACDAT)
/I2S_LRCK: U1.7 (GPIO2), U3.5 (DACLRC), U3.7 (ADCLRC)
/I2S_MCLK: R33.1, U1.17 (GPIO12)
/I2S_SCLK: U1.9 (GPIO4), U3.3 (BCLK)
/LCD_BK: J3.8, U1.42 (GPIO38)
/LCD_CS: J3.7, U1.41 (GPIO37)
/LCD_DC: J3.6, U1.40 (GPIO36)
/LCD_NRST: J3.5, U1.39 (GPIO35)
/LCD_SCLK: J3.3, U1.37 (GPIO33)
/LCD_SDO: J3.4, U1.38 (GPIO34)
/LNA_IN: C43.1, L1.2, U1.2 (LNA_IN)
/NRST: C51.1, Q1.3 (C), R26.1, SW1.1, U1.56 (CHIP_PU)
/RTS: J1.3, Q1.2 (E), R19.1
/TCK: J12.5, U1.43 (MTCK)
/TDI: J12.3, U1.46 (MTDI)
/TDO: J12.4, U1.44 (MTD0)
/TMS: J12.2, U1.47 (MTMS)
/UART0_RX: J1.1, U1.49 (U0RXD)
/UART0_TX: J1.2, U1.48 (U0TXD)
/USB_DM: R35.1, U1.25 (GPIO19)
/USB_DP: R34.1, U1.26 (GPIO20)
/VDD_3P3: C7.1, L2.2, U1.3 (VDD3P3), U1.4 (VDD3P3)
GND: C1.2, C2.2, C3.2, C4.2, C5.2, C6.2, C7.2, C8.2, C31.2, C32.2, C33.2, C34.2, C35.2, C36.2, C37.2, C38.2, C39.2, C40.2, C41.2, C42.2, C43.2, C44.1, C45.2, C46.2, C47.1, C48.2, C51.2, C52.2, J1.5, J2.2 (GND), J3.1, J11.5 (GND), J11.6 (Shield), J12.6, SW1.2, SW4.2, U1.57 (GND), U2.1 (GND), U3.11 (HPGND), U3.15 (AGND), U3.21 (MODE), U3.22 (CSB), U3.28 (DCGND); also elsewhere on the board
unnamed: C2.1, R28.1, Y1.1
unnamed: C3.1, U1.52 (XTAL_N), Y1.3
unnamed: C45.1, C46.1, U3.16 (VMID)
unnamed: J11.2 (D-), R35.2
unnamed: J11.3 (D+), R34.2
unnamed: Q1.1 (B), R18.2
unnamed: Q2.1 (B), R19.2
unnamed: R28.2, U1.53 (XTAL_P)
unnamed: TP1.1, U1.23 (DAC_1)
unnamed: TP2.1, U1.24 (DAC_2)
unnamed: TP3.1, U1.12 (GPIO7)
unnamed: TP4.1, U1.13 (GPIO8)
unnamed: TP5.1, U1.16 (GPIO11)
unnamed: TP6.1, U1.28 (GPIO21)
Vbus: J11.1 (VBUS); also elsewhere on the board
cv1: U1.14 (GPIO9); also elsewhere on the board
cv2: U1.15 (GPIO10); also elsewhere on the board
in_l: U3.20 (LLINEIN); also elsewhere on the board
in_r: U3.19 (RLINEIN); also elsewhere on the board
out_l: U3.12 (LOUT); also elsewhere on the board
out_r: U3.13 (ROUT); also elsewhere on the board

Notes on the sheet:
SPI2
Internal memory bus
approx. 9.6MHz cutoff to prevent I2C interference.

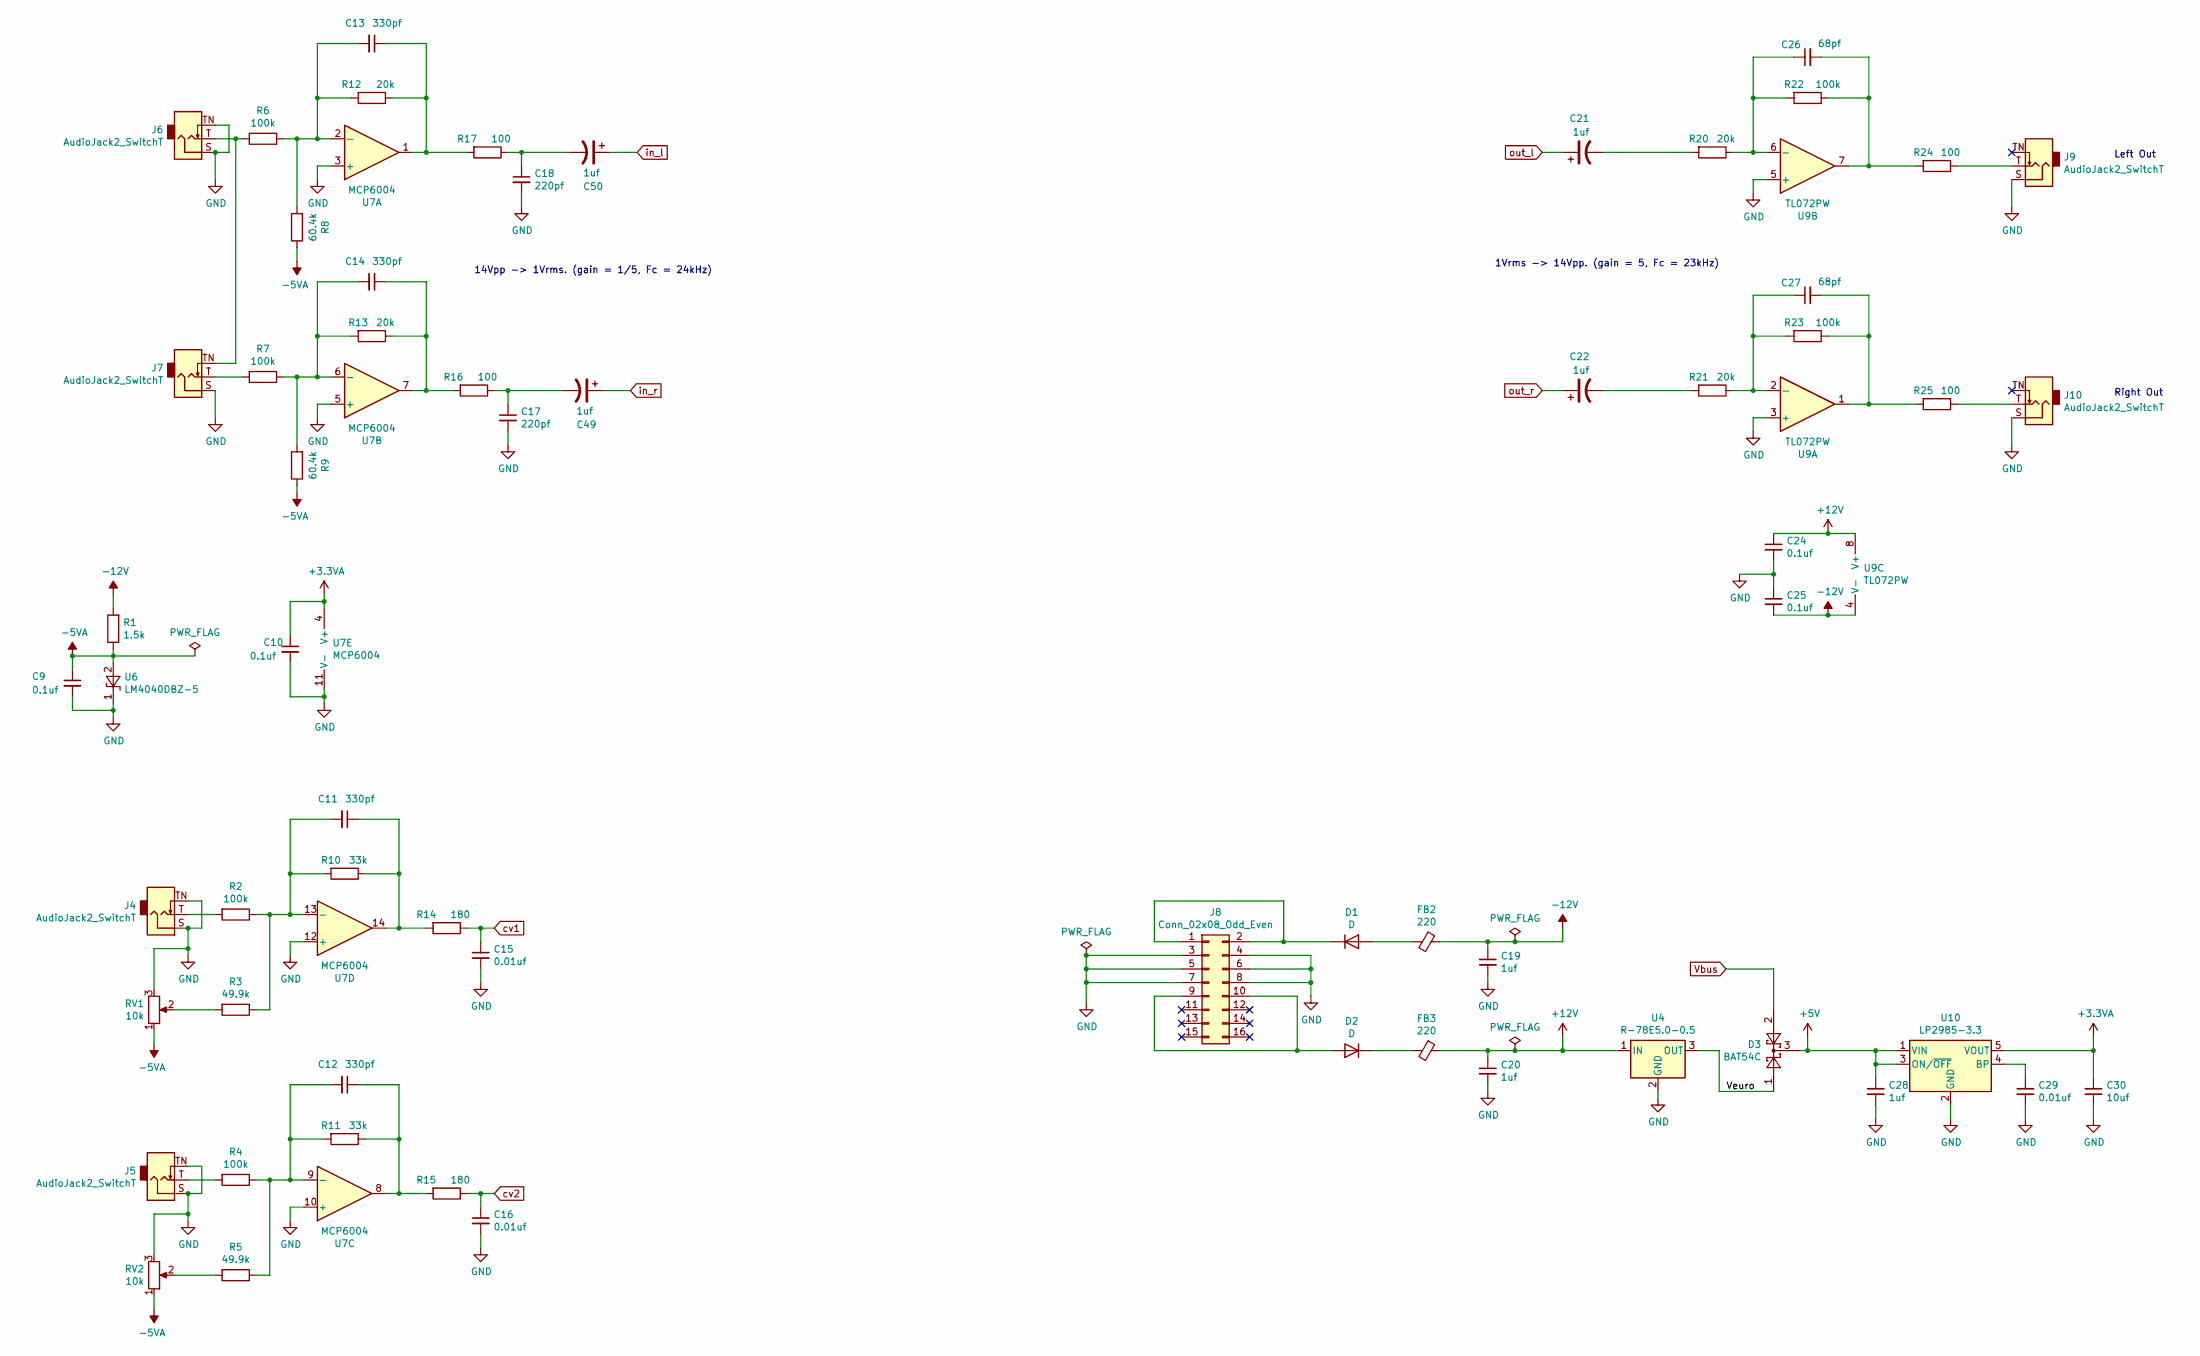
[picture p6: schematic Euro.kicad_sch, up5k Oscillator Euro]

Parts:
C9, C10, C24, C25: 0.1uf; C_0603
C11, C12, C13, C14: 330pf; C_0603
C15, C16, C29: 0.01uf; C_0603
C17, C18: 220pf; C_0603
C19, C20, C28: 1uf; C_0603
C21, C22, C49, C50: 1uf; CP_Elec_4x5.3
C26, C27: 68pf; C_0603
C30: 10uf; C_0805
D1, D2: D; D_SMA
D3: BAT54C; SOT-23
FB2, FB3: 220; R_0805
J4, J5, J6, J7, J9, J10: AudioJack2_SwitchT; Jack_3.5mm_QingPu_WQP-PJ398SM_Vertical_CircularHoles
J8: Conn_02x08_Odd_Even; 5103308-3
R1: 1.5k; R_0603
R2, R4, R6, R7, R22, R23: 100k; R_0603
R3, R5: 49.9k; R_0603
R8, R9: 60.4k; R_0603
R10, R11: 33k; R_0603
R12, R13, R20, R21: 20k; R_0603
R14, R15: 180; R_0603
R16, R17, R24, R25: 100; R_0603
RV1, RV2: 10k; Potentiometer_TT_P0915N
U4: R-78E5.0-0.5; Converter_DCDC_RECOM_R-78E-0.5_THT
U6: LM4040DBZ-5; SOT-23
U7: MCP6004; TSSOP-14_4.4x5mm_Pitch0.65mm
U9: TL072PW; TSSOP-8_4.4x3mm_Pitch0.65mm
U10: LP2985-3.3; SOT-23-5

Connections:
+3.3VA: C10.1, C30.1, U7.4 (V+), U10.5 (VOUT); also elsewhere on the board
+5V: C28.1, D3.3, U10.1 (VIN), U10.3 (ON/~OFF); also elsewhere on the board
+12V: C20.1, C24.1, FB3.1, U4.1 (IN), U9.8 (V+)
-5VA: C9.1, R1.1, R8.1, R9.1, RV1.1, RV2.1, U6.2 (A)
-12V: C19.1, C25.2, FB2.1, R1.2, U9.4 (V-)
/Sheet615690D3/Veuro: D3.1, U4.3 (OUT)
GND: C9.2, C10.2, C15.2, C16.2, C17.2, C18.2, C19.2, C20.2, C24.2, C25.1, C28.2, C29.2, C30.2, J4.S, J4.TN, J5.S, J5.TN, J6.S, J6.TN, J7.S, J8.3, J8.4, J8.5, J8.6, J8.7, J8.8, J9.S, J10.S, RV1.3, RV2.3, U4.2 (GND), U6.1 (K), U7.3 (+), U7.5 (+), U7.10 (+), U7.11 (V-), U7.12 (+), U9.3 (+), U9.5 (+), U10.2 (GND); also elsewhere on the board
unnamed: C11.1, R10.1, R14.2, U7.14
unnamed: C11.2, R2.1, R3.1, R10.2, U7.13 (-)
unnamed: C12.1, R11.1, R15.2, U7.8
unnamed: C12.2, R4.1, R5.1, R11.2, U7.9 (-)
unnamed: C13.1, R12.1, R17.2, U7.1
unnamed: C13.2, R6.1, R8.2, R12.2, U7.2 (-)
unnamed: C14.1, R13.1, R16.2, U7.7
unnamed: C14.2, R7.1, R9.2, R13.2, U7.6 (-)
unnamed: C17.1, C49.2, R16.1
unnamed: C18.1, C50.2, R17.1
unnamed: C21.2, R20.2
unnamed: C22.2, R21.2
unnamed: C26.1, R20.1, R22.2, U9.6 (-)
unnamed: C26.2, R22.1, R24.2, U9.7
unnamed: C27.1, R21.1, R23.2, U9.2 (-)
unnamed: C27.2, R23.1, R25.2, U9.1
unnamed: C29.1, U10.4 (BP)
unnamed: D1.1 (K), J8.1, J8.2
unnamed: D1.2 (A), FB2.2
unnamed: D2.1 (K), FB3.2
unnamed: D2.2 (A), J8.9, J8.10
unnamed: J4.T, R2.2
unnamed: J5.T, R4.2
unnamed: J6.T, J7.TN, R6.2
unnamed: J7.T, R7.2
unnamed: J9.T, R24.1
unnamed: J10.T, R25.1
unnamed: R3.2, RV1.2
unnamed: R5.2, RV2.2
Vbus: D3.2; also elsewhere on the board
cv1: C15.1, R14.1; also elsewhere on the board
cv2: C16.1, R15.1; also elsewhere on the board
in_l: C50.1; also elsewhere on the board
in_r: C49.1; also elsewhere on the board
out_l: C21.1; also elsewhere on the board
out_r: C22.1; also elsewhere on the board

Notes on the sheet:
14Vpp -> 1Vrms. (gain = 1/5, Fc = 24kHz)
Left Out
1Vrms -> 14Vpp. (gain = 5, Fc = 23kHz)
Right Out

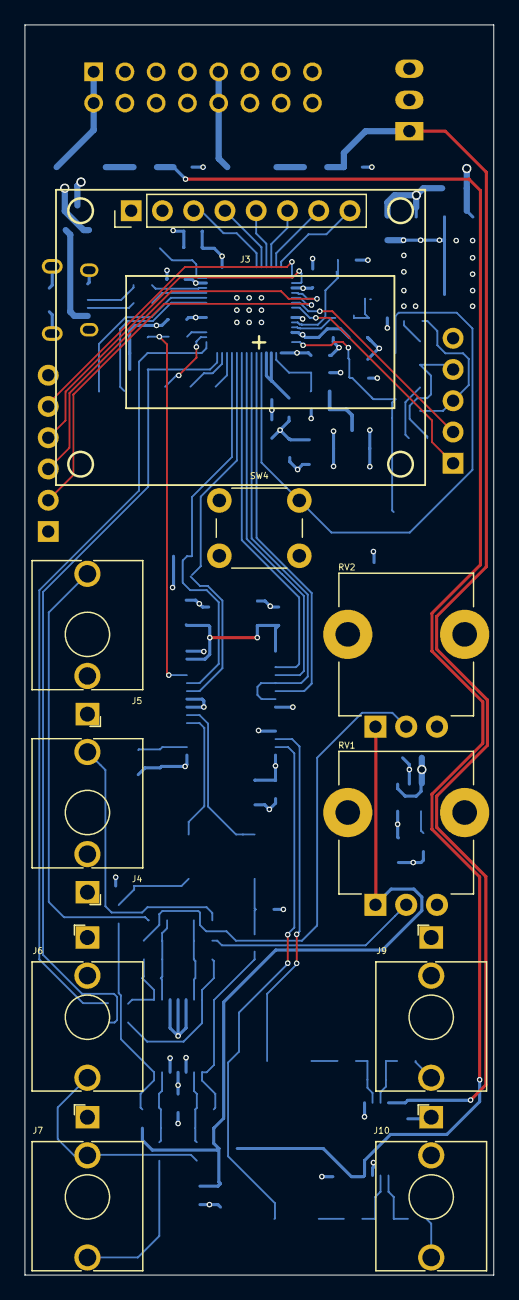
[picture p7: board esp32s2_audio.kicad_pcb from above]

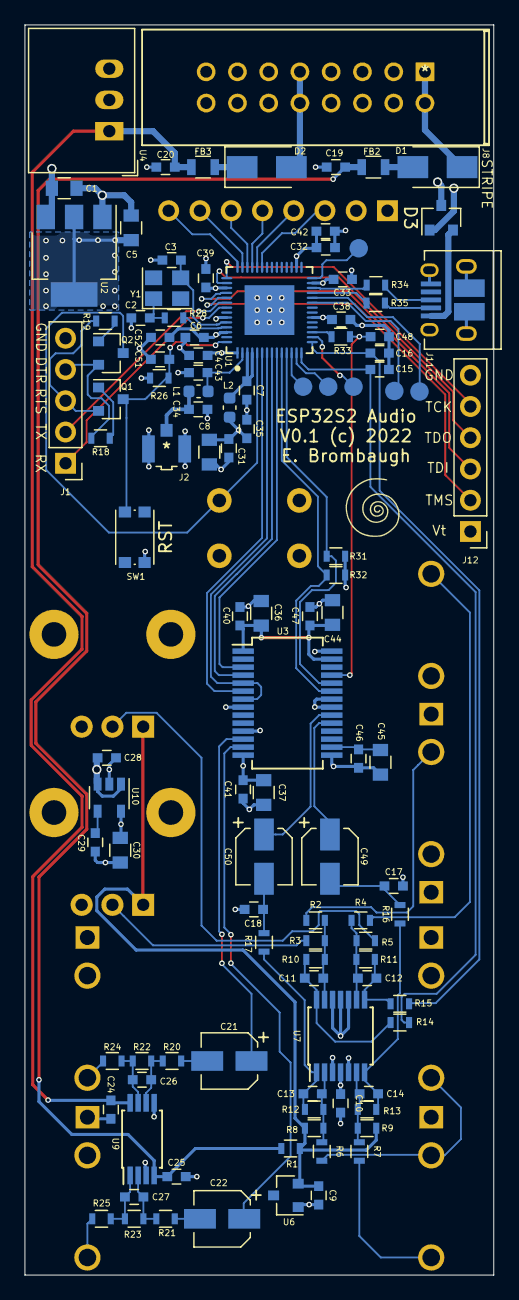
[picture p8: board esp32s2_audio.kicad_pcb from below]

Board: 4 copper layers, 38.1 x 101.6 mm, 124 parts (114 on the bottom side), 87 nets.

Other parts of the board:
Ref**: Val**; avatar_small

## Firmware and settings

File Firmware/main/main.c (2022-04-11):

/*
 * esp32s2_audio main.c
 * 01-23-22 E. Brombaugh
 */

#include <stdio.h>
#include "main.h"
#include "esp_timer.h"
#include "eb_adc.h"
#include "audio.h"
#include "eb_wm8731.h"
#include "button.h"
#include "st7735.h"
#include "gfx.h"
#include "menu.h"
#include "dsp_lib.h"
#include "splash.h"

static const char* TAG = "esp32_audio";

/* build version in simple format */
const char *fwVersionStr = "V0.1";

/* build time */
const char *bdate = __DATE__;
const char *btime = __TIME__;

/*
 * entry point
 */
void app_main(void)
{
	printf("\n\nESP32S2_Audio - Audio DSP module %s starting\n\r", fwVersionStr);
	printf("Build Date: %s\n\r", bdate);
	printf("Build Time: %s\n\r", btime);
	printf("\n");

	/* init ADC */
    ESP_LOGI(TAG, "Init ADC");
	eb_adc_init();
	
	/* init I2S */
    ESP_LOGI(TAG, "Init Audio");
	audio_init();
	
	/* init codec */
    ESP_LOGI(TAG, "Init WM8731 Codec");
	eb_wm8731_Init();
	eb_wm8731_Reset();
	eb_wm8731_Mute(0);
	
	/* init button */
    ESP_LOGI(TAG, "Init button");
	button_init();
	
	/* Init LCD */
	ESP_LOGI(TAG, "Init GFX");
	gfx_init(&ST7735_drvr);
	gfx_bitblt(0, 0, 160, 80, (uint16_t *)splash_png_565);
	gfx_set_forecolor(GFX_BLACK);
	gfx_set_backcolor(0xc7def6);
	gfx_drawstrctr(120, 20, "ESP32S2");
	gfx_drawstrctr(120, 30, "Audio");
	gfx_drawstrctr(120, 40, (char *)fwVersionStr);
	gfx_set_forecolor(GFX_WHITE);
	gfx_set_backcolor(GFX_BLACK);
	ST7735_setBacklight(1);
	vTaskDelay(3000/portTICK_RATE_MS);
		
	/* init menu */
    ESP_LOGI(TAG, "Init menu");
	menu_init();
	
	/* loop here forever */
    ESP_LOGI(TAG, "Looping...");
    while(1)
	{		
		menu_update();
		//printf("%5d %5d\n", adc_val[0], adc_val[1]);
		vTaskDelay(1);
    }
}

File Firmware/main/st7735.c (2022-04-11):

/*
 * ST7735.c - interface routines for ST7735 LCD on rp2040_audio.
 * shamelessly ganked from Adafruit_ST7735 library
 * 08-12-19 E. Brombaugh
 * 10-21-20 E. Brombaugh - updated for f405_codec_v2
 * 10-28-20 E. Brombaugh - updated for f405 feather + tftwing
 * 10-11-21 E. Brombaugh - updated for RP2040
 */

#include <stdio.h>
#include <string.h>
#include "freertos/FreeRTOS.h"
#include "freertos/task.h"
#include "esp_log.h"
#include "driver/spi_master.h"
#include "driver/gpio.h"
#include "st7735.h"

/* ----------------------- I/O definitions ----------------------- */

#define LCD_HOST    SPI2_HOST

#define PIN_NUM_MISO (-1)
#define PIN_NUM_MOSI 34
#define PIN_NUM_CLK  33
#define PIN_NUM_CS   37

#define PIN_NUM_DC   36
#define PIN_NUM_RST  35
#define PIN_NUM_BCKL 38

//To speed up transfers, every SPI transfer sends a bunch of lines. This define specifies how many. More means more memory use,
//but less overhead for setting up / finishing transfers. Make sure 240 is dividable by this.
#define PARALLEL_LINES 16

static const char* TAG = "st7735";

//This function is called (in irq context!) just before a transmission starts. It will
//set the D/C line to the value indicated in the user field.
void lcd_spi_pre_transfer_callback(spi_transaction_t *t)
{
    int dc=(int)t->user;
    gpio_set_level(PIN_NUM_DC, dc);
}

#define ST_CMD            0x100
#define ST_CMD_DELAY      0x200
#define ST_CMD_END        0x400

#define ST77XX_NOP        0x00
#define ST77XX_SWRESET    0x01
#define ST77XX_RDDID      0x04
#define ST77XX_RDDST      0x09

#define ST77XX_SLPIN      0x10
#define ST77XX_SLPOUT     0x11
#define ST77XX_PTLON      0x12
#define ST77XX_NORON      0x13

#define ST77XX_INVOFF     0x20
#define ST77XX_INVON      0x21
#define ST77XX_DISPOFF    0x28
#define ST77XX_DISPON     0x29
#define ST77XX_CASET      0x2A
#define ST77XX_RASET      0x2B
#define ST77XX_RAMWR      0x2C
#define ST77XX_RAMRD      0x2E

#define ST77XX_PTLAR      0x30
#define ST77XX_COLMOD     0x3A
#define ST77XX_MADCTL     0x36

#define ST77XX_MADCTL_MY  0x80
#define ST77XX_MADCTL_MX  0x40
#define ST77XX_MADCTL_MV  0x20
#define ST77XX_MADCTL_ML  0x10
#define ST77XX_MADCTL_RGB 0x08
#define ST77XX_MADCTL_MH  0x04


#define ST77XX_RDID1      0xDA
#define ST77XX_RDID2      0xDB
#define ST77XX_RDID3      0xDC
#define ST77XX_RDID4      0xDD

#define ST7735_SCRLAR     0x33
#define ST7735_VSCSAD     0x37

#define ST7735_FRMCTR1    0xB1
#define ST7735_FRMCTR2    0xB2
#define ST7735_FRMCTR3    0xB3
#define ST7735_INVCTR     0xB4
#define ST7735_DISSET5    0xB6

#define ST7735_PWCTR1     0xC0
#define ST7735_PWCTR2     0xC1
#define ST7735_PWCTR3     0xC2
#define ST7735_PWCTR4     0xC3
#define ST7735_PWCTR5     0xC4
#define ST7735_VMCTR1     0xC5

#define ST7735_GMCTRP1    0xE0
#define ST7735_GMCTRN1    0xE1

#define ST7735_PWCTR6     0xFC

/* swap bytes */
#define __REVSH(x) ((((x)>>8)&0xff)|(((x)&0xff)<<8))

/* high level driver interface */
GFX_DRIVER ST7735_drvr =
{
	ST7735_TFTHEIGHT,
	ST7735_TFTWIDTH,
	ST7735_init,
	ST7735_setRotation,
    ST7735_Color565,
    ST7735_ColorRGB,
	ST7735_fillRect,
	ST7735_drawPixel,
	ST7735_bitblt
};

/* ----------------------- private variables ----------------------- */
static spi_device_handle_t spi;

// Initialization command sequence
const static uint16_t
  initlst[] = {
#if 0
    // ST7735B
    ST77XX_SWRESET | ST_CMD,        //  1: Software reset, no args, w/delay
    ST_CMD_DELAY | 50,              //  50 ms delay
    ST77XX_SLPOUT | ST_CMD ,        //  2: Out of sleep mode, no args, w/delay
	ST_CMD_DELAY | 500,             //  500 ms delay
    ST77XX_COLMOD | ST_CMD ,        //  3: Set color mode
      0x50,                         //     16-bit color
	ST_CMD_DELAY | 10,              //     10 ms delay
    ST7735_FRMCTR1 | ST_CMD ,       //  4: Frame rate control
      0x00,                         //     fastest refresh
      0x06,                         //     6 lines front porch
      0x03,                         //     3 lines back porch
	ST_CMD_DELAY | 10,              //     10 ms delay
    ST77XX_MADCTL | ST_CMD ,        //  5: Mem access ctrl (directions), 1 arg:
      0x08,                         //     Row/col addr, bottom-top refresh
    ST7735_DISSET5 | ST_CMD,        //  6: Display settings #5, 2 args:
      0x15,                         //     1 clk cycle nonoverlap, 2 cycle gate
                                    //     rise, 3 cycle osc equalize
      0x02,                         //     Fix on VTL
    ST7735_INVCTR | ST_CMD,         //  7: Display inversion control, 1 arg:
      0x0,                          //     Line inversion
    ST7735_PWCTR1 | ST_CMD,         //  8: Power control, 2 args + delay:
      0x02,                         //     GVDD = 4.7V
      0x70,                         //     1.0uA
    ST_CMD_DELAY | 10,              //     10 ms delay
    ST7735_PWCTR2 | ST_CMD,         //  9: Power control, 1 arg, no delay:
      0x05,                         //     VGH = 14.7V, VGL = -7.35V
    ST7735_PWCTR3 | ST_CMD,         // 10: Power control, 2 args, no delay:
      0x01,                         //     Opamp current small
      0x02,                         //     Boost frequency
    ST7735_VMCTR1 | ST_CMD,         // 11: Power control, 2 args + delay:
      0x3C,                         //     VCOMH = 4V
      0x38,                         //     VCOML = -1.1V
    ST_CMD_DELAY | 10,              //     10 ms delay
    ST7735_PWCTR6 | ST_CMD,         // 12: Power control, 2 args, no delay:
      0x11,
      0x15,
    ST7735_GMCTRP1 | ST_CMD,        // 13: Gamma Adjustments (pos. polarity), 16 args + delay:
      0x09, 0x16, 0x09, 0x20,       //     (Not entirely necessary, but provides
      0x21, 0x1B, 0x13, 0x19,       //      accurate colors)
      0x17, 0x15, 0x1E, 0x2B,
      0x04, 0x05, 0x02, 0x0E,
    ST7735_GMCTRN1 | ST_CMD,        // 14: Gamma Adjustments (neg. polarity), 16 args + delay:
      0x0B, 0x14, 0x08, 0x1E,       //     (Not entirely necessary, but provides
      0x22, 0x1D, 0x18, 0x1E,       //      accurate colors)
      0x1B, 0x1A, 0x24, 0x2B,
      0x06, 0x06, 0x02, 0x0F,
    ST_CMD_DELAY | 10,              //     10 ms delay
    ST77XX_CASET | ST_CMD,          // 15: Column addr set, 4 args, no delay:
      0x00, 0x02,                   //     XSTART = 2
      0x00, 0x81,                   //     XEND = 129
    ST77XX_RASET | ST_CMD,          // 16: Row addr set, 4 args, no delay:
      0x00, 0x02,                   //     XSTART = 1
      0x00, 0x81,                   //     XEND = 160
    ST77XX_NORON | ST_CMD,          // 17: Normal display on, no args, w/delay
    ST_CMD_DELAY | 10,              //     10 ms delay
    ST77XX_DISPON | ST_CMD,         // 18: Main screen turn on, no args, delay
    ST_CMD_DELAY | 500,             //     255 = max (500 ms) delay
	ST_CMD_END                      //  END OF LIST
#else
    // mini is ST7735R
    // 7735R init, part 1 (red or green tab)
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

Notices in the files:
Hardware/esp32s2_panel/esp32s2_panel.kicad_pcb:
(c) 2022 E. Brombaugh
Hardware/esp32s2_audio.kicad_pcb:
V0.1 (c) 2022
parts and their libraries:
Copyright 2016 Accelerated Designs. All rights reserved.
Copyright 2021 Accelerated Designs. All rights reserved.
